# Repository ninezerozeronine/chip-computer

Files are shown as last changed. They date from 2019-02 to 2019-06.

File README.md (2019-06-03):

# 8 bit Computer

   

This is a project to make a basic but fully functional 8 bit computer 
using 7400 series ICs.

The full docs can be found on the Read the Docs: https://eight-bit-computer.readthedocs.io/

# Docs

To build the docs on mac run:

    make clean
    make html

in `docs`.

To build the docs in windows run:

    sphinx-build.exe . _build

in `docs`. This also runs the apidoc command on build with a convenience function in conf.py.

# Tests

To run the tests, run:

    tox -e test

in the root directory.

Run:

    tox -e test -- -m "not slow"

To avoid the slow checks.

To generate a coverage report run:

    tox -e cov

in the root directory.

# Release

    python setup.py sdist bdist_wheel
    python -m twine upload dist/*

# License

The content of this project itself is licensed under the
[Attribution-ShareAlike 4.0 International
license](http://creativecommons.org/licenses/by-sa/4.0/), and any source code used
in conjunction with the project is licensed under the [MIT
license](http://opensource.org/licenses/mit-license.php).

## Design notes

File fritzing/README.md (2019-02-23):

The custom_parts folder contains copies of the bins and parts folders that Fritzing creates in the user home area (C:\Users\<user>\My Documents\Fritzing on Windows).

It's primarily a backup for the custom parts used in the design stage, but feel free to try and modify the files (bins/my_parts.fzb seems to be the one to edit) if you would like to copy them for use in your own project.

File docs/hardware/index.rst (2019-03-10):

Hardware
========

.. toctree::
   :maxdepth: 2
   :caption: Hardware:

   hct_vs_ls
   fanout
   materials_and_tools
   edge_detection
   debouncing
   eeprom_programmer
   safe_clock_enable
   open_collector

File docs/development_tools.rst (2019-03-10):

Development Tools
=================

.. _logisim:

Logisim
-------

.. _fritzing:

Fritzing
--------

.. _falstad:

Falstad Circuit Simulator
-------------------------

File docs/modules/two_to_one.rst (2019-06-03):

.. _two_to_one:

2:1 Selector
============

The 2:1 selector outputs one of two 8 bit inputs. Also known as a multiplexer.

Interface and Operation
-----------------------

This is the interface of a 2:1 selector:

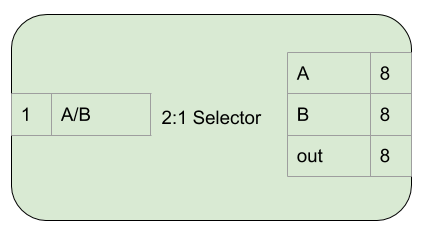
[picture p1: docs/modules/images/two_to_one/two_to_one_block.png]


This is how it operates:

+------+-----------+-----------------------------------------------+
| Name | Bit width | Description                                   |
+======+===========+===============================================+
| A    | 8         | First input                                   |
+------+-----------+-----------------------------------------------+
| B    | 8         | Second input                                  |
+------+-----------+-----------------------------------------------+
| out  | 8         | Output, either A or B.                        |
+------+-----------+-----------------------------------------------+
| A/B  | 1         | When low, A is output, when high, B is output |
+------+-----------+-----------------------------------------------+

Implementation
--------------

- Two 74HCT157s are used to choose between the two inputs.
- LEDs with current limiting resistors are used to display the output.

Due to 2:1 selectors being required in different parts of the computer,
the layout on the breadboard of A, B and out sometimes need to differ.

This is the `A B out` layout:

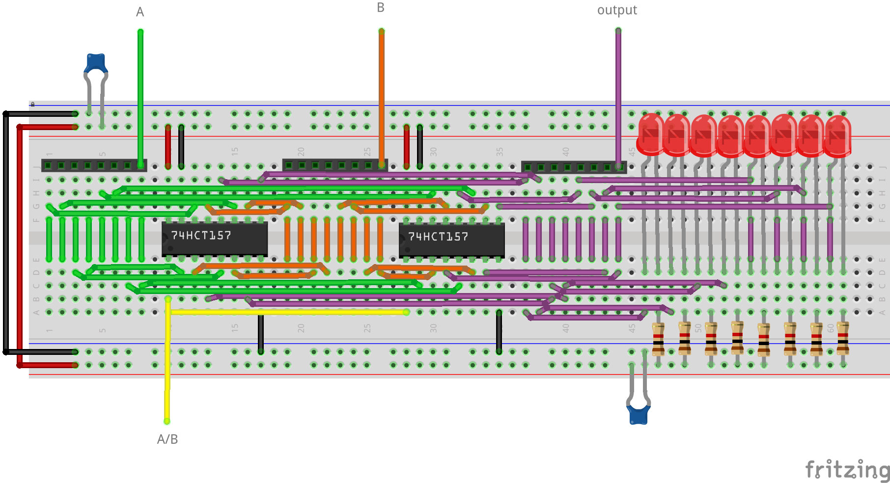
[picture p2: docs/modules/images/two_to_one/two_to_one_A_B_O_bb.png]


This is the `out A B` layout:

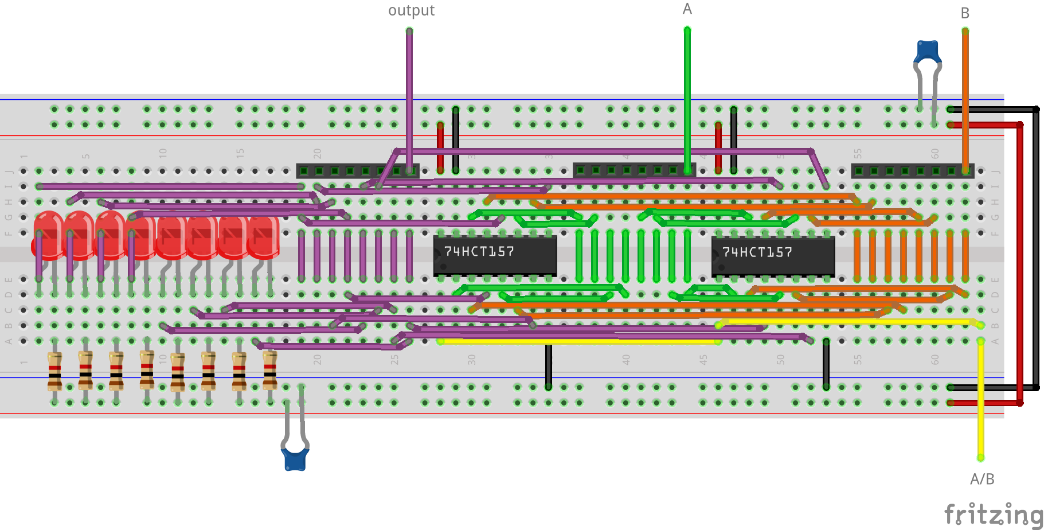
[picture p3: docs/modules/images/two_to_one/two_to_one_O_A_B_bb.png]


Different coloured wires are used in the :ref:`fritzing` images above to help
track the A, B and out bits. When creating the computer only green wire was
available :(.

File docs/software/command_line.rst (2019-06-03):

Command Line Tools
==================

.. _command_line_assemble:

ebc-assemble
------------

.. argparse::
   :ref: eight_bit_computer.cli.get_assemble_parser
   :prog: ebc-assemble

.. _command_line_gen_roms:

ebc-gen-roms
------------

.. argparse::
   :ref: eight_bit_computer.cli.get_gen_roms_parser
   :prog: ebc-gen-roms

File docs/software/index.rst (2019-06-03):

Software
========

.. toctree::
   :maxdepth: 2
   :caption: Key functionality:

   assembler

.. toctree::
   :maxdepth: 2
   :caption: Command line utilities:

   command_line

.. toctree::
   :maxdepth: 3
   :caption: Source Documentation:

   source/eight_bit_computer

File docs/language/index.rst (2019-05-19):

.. _language:

Language
========

The language of the computer is broadly defined with the following terms:

+--------------------------+---------------------------------------------------------------------------------------------------------------------------------------------------------------------------------------------------------------+
| Name                     | Description                                                                                                                                                                                                   |
+==========================+===============================================================================================================================================================================================================+
| Assembly / Assembly code | Collective name for operations in sequence to form a program. The input to the assembler.                                                                                                                     |
+--------------------------+---------------------------------------------------------------------------------------------------------------------------------------------------------------------------------------------------------------+
| Token                    | A set of characters separated from other characters by spaces at the beginning and end. E.g the assembly line ``LOAD [#123] B`` has 3 tokens: ``LOAD`` ``[#123]`` and ``B``.                                  |
+--------------------------+---------------------------------------------------------------------------------------------------------------------------------------------------------------------------------------------------------------+
| Operation                | A specific, simple step that the computer can perform. E.g. add the value in a given register to the accumulator, or copy a value in one register to another.                                                 |
+--------------------------+---------------------------------------------------------------------------------------------------------------------------------------------------------------------------------------------------------------+
| Operation code / Op code | A unique code used to identify an operation, e.g. ``AND``, ``JUMP``, or ``ADD``.                                                                                                                              |
+--------------------------+---------------------------------------------------------------------------------------------------------------------------------------------------------------------------------------------------------------+
| Operation Argument       | A value passed to an operation to specify it's behaviour. E.g. passing ``B`` to the ``ADD`` operation to specify that the value in register B should be added to the accumulator register.                    |
+--------------------------+---------------------------------------------------------------------------------------------------------------------------------------------------------------------------------------------------------------+
| Instruction              | A fully specified operation, e.g. a copy from B to C or setting the A register to a value. Effectively a line of assembly.                                                                                    |
+--------------------------+---------------------------------------------------------------------------------------------------------------------------------------------------------------------------------------------------------------+
| Instruction byte         | A byte that uniquely identifies an instruction.                                                                                                                                                               |
+--------------------------+---------------------------------------------------------------------------------------------------------------------------------------------------------------------------------------------------------------+
| Machine code             | Collective name for the bytes in program memory that form the instructions and constants of a program. The assembler generates machine code.                                                                  |
+--------------------------+---------------------------------------------------------------------------------------------------------------------------------------------------------------------------------------------------------------+
| Machine code byte        | A byte that makes up machine code. Could be an instruction or an constant value.                                                                                                                              |
+--------------------------+---------------------------------------------------------------------------------------------------------------------------------------------------------------------------------------------------------------+
| Microcode                | The pattern of bits that determine the control signals to operate the computer to complete an instruction. The Control Unit contains microcode.                                                               |
+--------------------------+---------------------------------------------------------------------------------------------------------------------------------------------------------------------------------------------------------------+
| Microcode Step           | A single transfer of data via the bus or action of a module occurring on a rising clock edge. The smallest, most specific level of control. An instruction is completed by doing a number of microcode steps. |
+--------------------------+---------------------------------------------------------------------------------------------------------------------------------------------------------------------------------------------------------------+

See the `language table <../_static/language_table.html>`_ (or
:download:`download it <../_static/language_table.csv>`) for a complete listing
of all the machine code and operations with their arguments. The table is
sortable by clicking on the headers (but it's a little slow).

.. toctree::
   :maxdepth: 2
   :caption: Language Elements:

   assembly
   machine_code
   micro_code

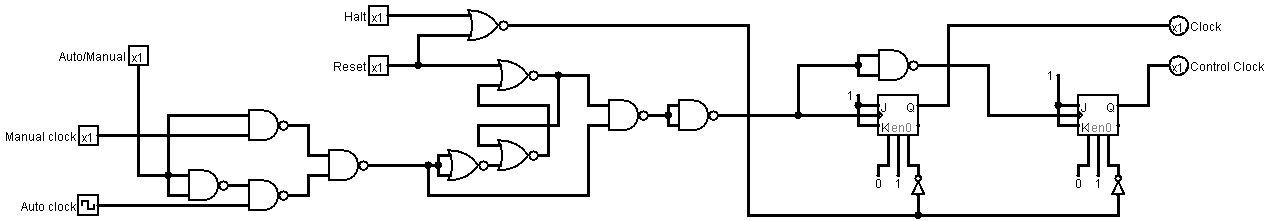
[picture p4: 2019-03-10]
docs/modules/images/clock/clock_schematic_reality.png

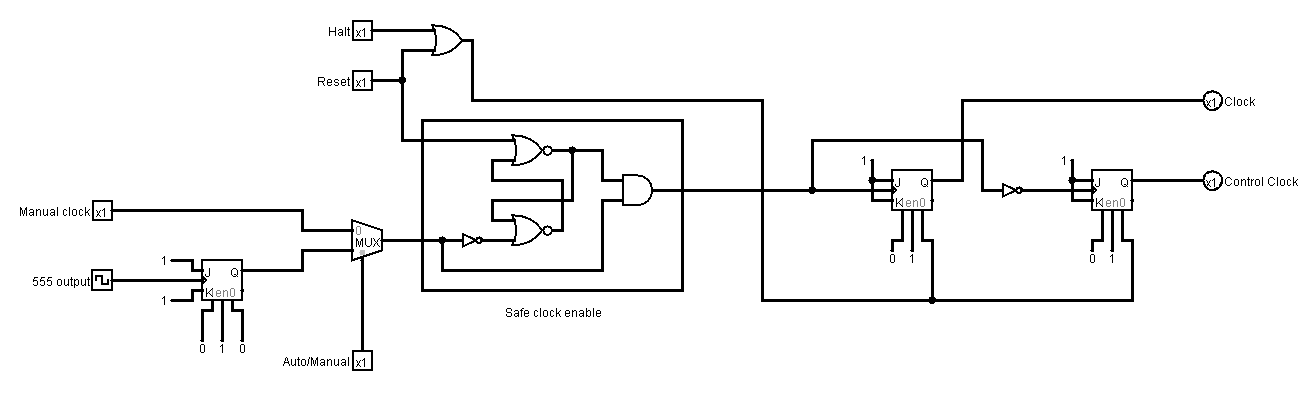
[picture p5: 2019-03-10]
docs/modules/images/clock/clock_schematic_ideal.png

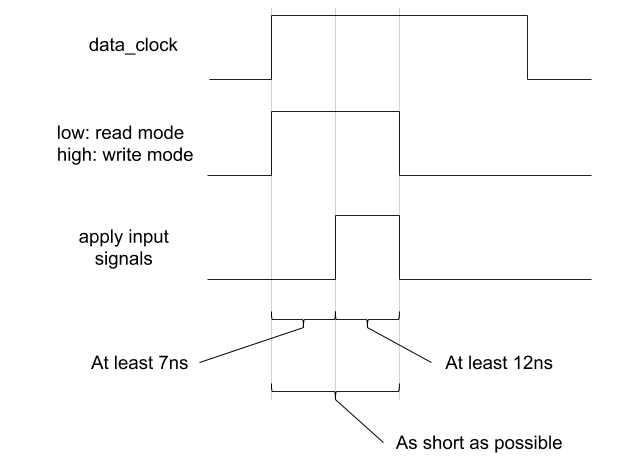
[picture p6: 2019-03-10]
docs/modules/images/ram/ideal_ram_write_control.png

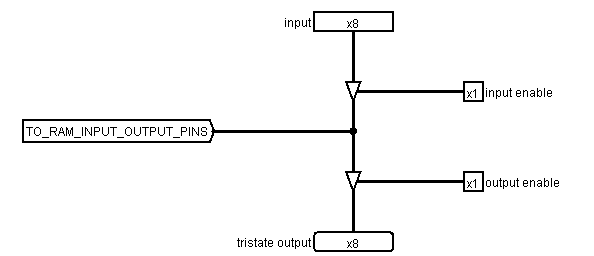
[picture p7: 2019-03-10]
docs/modules/images/ram/input_output_buffers.png

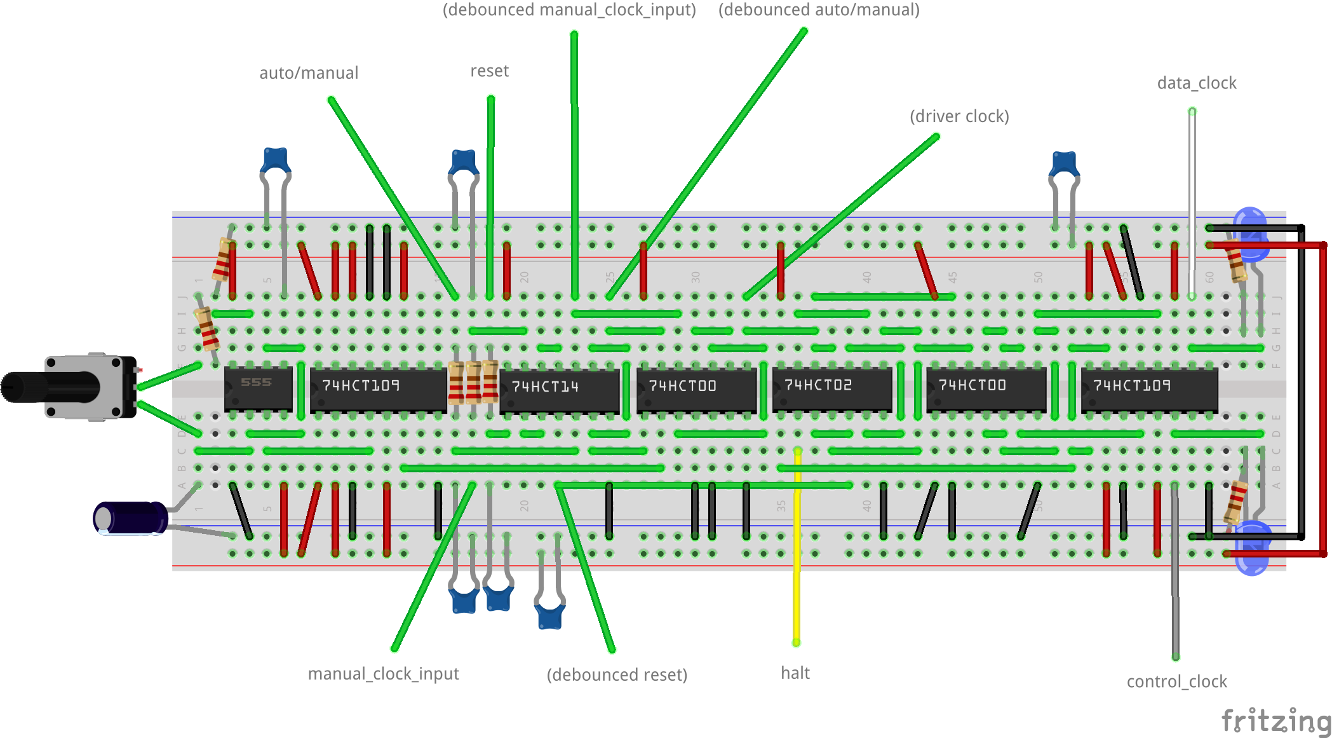
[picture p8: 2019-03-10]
docs/modules/images/clock/clock_bb.png

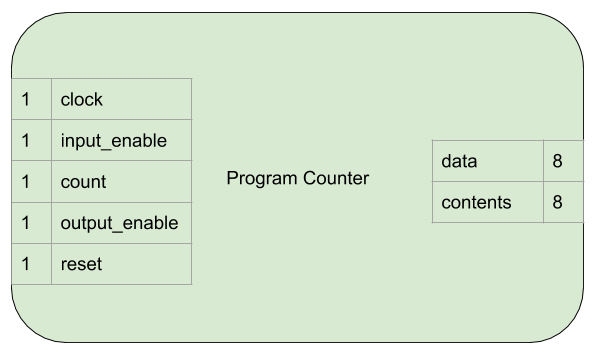
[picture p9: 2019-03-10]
docs/modules/images/program_counter/program_counter_block.png

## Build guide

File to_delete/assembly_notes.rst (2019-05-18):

Some example assembly::

    // This is a comment

        LOAD [#15] ACC
        SET B #0b11010101

    @label1
        COPY ACC A
        COPY A B
        COPY B C
        STORE C [$variable]

    // Another comment
    @label2
        SET SP #255
        JUMP @label1

Handling Constants
-------------------

It's mostly the job of the instruction to identify what it thinks might be a
constant then return this back to the assembler. It can also identify if a
constant (unexpected token) has been given and raise an error.

An instruction will return something like::

    [
        {
            "machine_code": "01101100",
            "constant": "",
        },
        {
            "machine_code": "",
            "constant": "@label",
        },
        {
            "machine_code": "",
            "constant": "#number",
        }
    ]

The constants are then checked by the assembler to see if they conform to
standards and identified. The machine code is then updated to::

    [
        {
            "machine_code": "01101100",
            "constant": "",
        },
        {
            "machine_code": "",
            "constant": "@label",
            "constant_type": "label",
        },
        {
            "machine_code": "",
            "constant": "#number",
            "constant_type": "number",
            "number_value": 123,
        }
    ]

Constants can be @labels, $variables or #numbers

Validating numbers
------------------

#numbers in the assembly are first attempted to be cast to ints. Thay can be
specified in the same way integers are specified in python, e.g.:

- 123
- 0xff
- 0b100101
- 0o77
  
If a number is greater than 255 or less than 128 it's an assembly error.

Assembly errors
---------------

The user needs to know which line of the assembly file an error occurred on.

Should these be execptions?

Assembly steps
--------------

Can raise assembly errors and parsing errors?

Go through every line and extract the following info::

    {
        "line_no": 34,
        "raw_line": "  COPY   ACC   A",
        "cleaned_line": "COPY ACC A",
        "is_label": True
        "label": "@label1",
        "assigned_labels": [],
        
        "variables": [],
        "numbers": [],
        "constants": [],
    }         

Get machine code for the line from the instruction, add it to the dict. Parser
is passed list of constants. Catch Parsing error and re raise as assembly error.

Check numbers are valid - Raise assembly error if there's a bad number

Check for references to labels that haven't been declared. Raise assembly error
if something goes wrong.

Warn about unused labels

Aggregate labels onto real instructions

Warn about multiple labels on single instruction

Exceptions
----------

Could raise exceptions to handle assembly errors?

These get raised by the language parsers:

- InstructionParsingError

  - Constant passed when it wasn't expected
  - Too many arguments passed

These get raised during line processing

- LineProcessingError

  - Invalid label definition
  - Invalid variable definition
  - Invalid label used
  - Invalid variable used
  - 

These get raised during assembly:

- AssemblyError

  - InstructionBytesError
  - UndeclaredLabelError
  - GlobalVariablesError
  - IncorrectNumberError
  - IncorrectLabelNameError
  - IncorrectVariableNameError
  - ParsingError
  - UnmatchedInstructionError

Have a layer of indirection between the assembly and the instructions.
All the instructions need to know is that they've been passed an
immediate value. It's up to the assembler to eventually resolve that immediate
value into:

- An actual number (43)
- A reference to a label (e.g for a jump instruction)

It's the assemblers job to resolve references to @labels (and eventually
$variables). The instructions will need to pass back some kind of placeholder.

Does the assembler just need to say: "You were passed a constant" to the
instruction? And the instruction will pass say: "Here's where to insert that
constant in the machine code"? It needs to be able to pass back some kind of
identifier so that an @label or $variable can later be resolved once it's buried
in the machine code.

What happens if there's some assembly like this::

        %My comment

    @label1
        COPY ACC A
        COPY A B
        COPY B C

    @label2
    @label3
    @label4
        COPY SP C
        COPY A B
        COPY B C

Do @label2, 3 and 4 all mean the COPY SP C line? No, this is invalid. the
assembly will fail

Here's some example data structures::

    assembly_line = {
        "input_line_no": 34,
        "input_line": "  COPY   ACC   A",
        "cleaned_input_line": "COPY ACC A",
        "labels": None,
    }

    machine_code_line {
        "data": "00101010",
    }

    machine_code_line {
        "data": "@label1",
    }

    machine_code_line {
        "data": "11010110",
        "label": "@label2"
    }

I quite like the idea of the machine_code_line structure. If the data is an
@label or $variable then the assembler will know to replace it.

Instructions can keep things simple and return a list of program bytes,
including anything immediate. eg::

    [
        "00101010",
        "IMM",
    ]

Then it's up to the assembler to replace the immediate values with the @label or
$variable in the original assembly line.

As some point the assembler will need to resolve the labels to actual lines in
the machine code.

The assembler needs to be able to cope with:

- LOAD [$variable] A
- LOAD [#123] A
- LOAD [@label] A <- weird, but whatever
- LOAD [ACC] B
- STORE A [$variable]
- STORE A [@label] <- weird, but whatever
- STORE A [#123]
- SET A #123
- JUMP @label
- JUMP B
- JUMP $variable  <- weird, but whatever
- JUMP_IF_FLAG ZERO #123
- JUMP_IF_FLAG ZERO @label
  
Perhaps $variables, @labels and #numbers get converted to IMM by the assembler?
The brackets can just be in the assembly side as a reminder when programming?

Instructions only need to be able to deal with ACC, A, B, C, SP, PC, IMM?

Given ``LOAD [$variable] A`` the assembler should only replace $variable to
arrive at: ``LOAD [IMM] A``.

A user shouldn't be able to write things like:

- ``LOAD [IMM] A``
- ``LOAD [SP+/-] A``
- ``LOAD [SP+/-] IMM``
- ``JUMP SP+/-``
  
The assembler won't end up being able to replace that with a real value later.
It would also trick the instruction matcher as the assembler is meant to pass
IMM to designate an immediate value.

An instruction should be responsible for determining if the line is valid.

Should the assembler inform the instruction if it's being passed a
placeholder/immediate value?

 Could do:

- A list of allowed tokens in assembly files
- A special function that the assembler calls if it's passing through a
  placeholder

We need to be able to point the user back at at line in the assembly file to:

- Warn if a line has multiple labels
- Warn if a label is unused
- Error if you try to jump to an undefined label
  
Does this mean resole @labels while parsing the raw lines?

Constants start with a # but could be int, binary or hex. #i #b #h and it
defaults to int? Use python notation and then ``int(value_string, 0)`` e.g.

- #123
- #0x4f
- #0o77
- #0b1001010

Tests!

- Assembly files with only @labels in
- What happens when you do LOAD [[#123]] A
- Assembly files with only comments
- assembly files with only empty lines
- Passing nothing into a LOAD, e.g LOAD [] A

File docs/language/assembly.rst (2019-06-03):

Assembly
========

Assembly code provides a way to specify instructions for the computer to
perform in a more human readable from than machine code

Assembly operations and arguments to specify their behaviour can be saved in an
assembly file and passed to an assembler to convert them to machine code that
the computer can then execute.

These are the operations and other assembly constructs that can be used to
create a valid assembly file.

Arithmetic Operations
---------------------

ADD
^^^

The ``ADD`` operation adds the value held in the specified module (or a
constant) to the accumulator. The ALU flags generated by this operation are
stored.

The possible usages are:

 - ``ADD A``
 - ``ADD B``
 - ``ADD C``
 - ``ADD CONST``

ADDC
^^^^

SUB
^^^

SUBB
^^^^

LSHIFT
^^^^^^

LSHIFTC
^^^^^^^

INCR
^^^^

DECR
^^^^

Data Operations
---------------

COPY
^^^^

The ``COPY`` operation copies the value from a source module to a destination
module. This overwrites the current value of the destination register. It
requires a single machine code byte in program memory.

It is used by specifying the source module as the first argument and the
destination module as the second.

The possible usages are:

 - ``COPY ACC A``
 - ``COPY ACC B``
 - ``COPY ACC C``
 - ``COPY ACC SP``
 - ``COPY A ACC``
 - ``COPY A B``
 - ``COPY A C``
 - ``COPY A SP``
 - ``COPY B ACC``
 - ``COPY B A``
 - ``COPY B C``
 - ``COPY B SP``
 - ``COPY C ACC``
 - ``COPY C A``
 - ``COPY C B``
 - ``COPY C SP``
 - ``COPY PC ACC``
 - ``COPY PC A``
 - ``COPY PC B``
 - ``COPY PC C``
 - ``COPY PC SP``
 - ``COPY SP ACC``
 - ``COPY SP A``
 - ``COPY SP B``
 - ``COPY SP C``

LOAD
^^^^

The ``LOAD`` operation loads a value from data memory into a module.

It is used by specifying the position in memory as the first argument and the
destination module as the second. The position in memory can be a module or a
constant and is encased in square parentheses.

The possible usages are:

 - ``LOAD [ACC] ACC``
 - ``LOAD [ACC] A``
 - ``LOAD [ACC] B``
 - ``LOAD [ACC] C``
 - ``LOAD [A] ACC``
 - ``LOAD [A] A``
 - ``LOAD [A] B``
 - ``LOAD [A] C``
 - ``LOAD [B] ACC``
 - ``LOAD [B] A``
 - ``LOAD [B] B``
 - ``LOAD [B] C``
 - ``LOAD [C] ACC``
 - ``LOAD [C] A``
 - ``LOAD [C] B``
 - ``LOAD [C] C``
 - ``LOAD [PC] ACC``
 - ``LOAD [PC] A``
 - ``LOAD [PC] B``
 - ``LOAD [PC] C``
 - ``LOAD [SP] ACC``
 - ``LOAD [SP] A``
 - ``LOAD [SP] B``
 - ``LOAD [SP] C``
 - ``LOAD [CONST] ACC``
 - ``LOAD [CONST] A``
 - ``LOAD [CONST] B``
 - ``LOAD [CONST] C``

STORE
^^^^^

PROGLOAD
^^^^^^^^

PROGSTORE
^^^^^^^^^

PUSH
^^^^

POP
^^^

SET
^^^

The ``SET`` operation will set a module in the computer to a given
constant value.

It is used by specifying a module as the first argument, then the value to set
it to as a constant.

It requires two machine code bytes in program memory. Consider the
:ref:`setzero` operation if the constant is zero.

The possible usages are:

 - ``SET ACC CONST``
 - ``SET A CONST``
 - ``SET B CONST``
 - ``SET C CONST``
 - ``SET SP CONST``

.. _setzero:

SETZERO
^^^^^^^

Program Control Operations
--------------------------

NOOP
^^^^

JUMP
^^^^

The ``JUMP`` operation will set the program counter to a value.

The possible usages are:

 - ``JUMP ACC``
 - ``JUMP A``
 - ``JUMP B``
 - ``JUMP C``
 - ``JUMP SP``
 - ``JUMP CONST``
 - ``JUMP [ACC]``
 - ``JUMP [A]``
 - ``JUMP [B]``
 - ``JUMP [C]``
 - ``JUMP [SP]``
 - ``JUMP [PC]``
 - ``JUMP [CONST]``

JUMP_IF_LT_ACC
^^^^^^^^^^^^^^

JUMP_IF_LTE_ACC
^^^^^^^^^^^^^^^

JUMP_IF_EQ_ACC
^^^^^^^^^^^^^^

JUMP_IF_GTEQ_ACC
^^^^^^^^^^^^^^^^

JUMP_IF_GT_ACC
^^^^^^^^^^^^^^

JUMP_IF_EQ_ZERO
^^^^^^^^^^^^^^^

JUMP_IF_POSITIVE_FLAG
^^^^^^^^^^^^^^^^^^^^^

JUMP_IF_NEGATIVE_FLAG
^^^^^^^^^^^^^^^^^^^^^

JUMP_IF_OVERFLOW_FLAG
^^^^^^^^^^^^^^^^^^^^^

The ``JUMP_IF_OVERFLOW_FLAG`` operation will set the program counter to the
value of a given constant if the overflow flag is high.

The possible usages are:

 - ``JUMP_IF_OVERFLOW_FLAG CONST``

JUMP_IF_NOT_OVERFLOW_FLAG
^^^^^^^^^^^^^^^^^^^^^^^^^

JUMP_IF_UNDERFLOW_FLAG
^^^^^^^^^^^^^^^^^^^^^^

JUMP_IF_NOT_UNDERFLOW_FLAG
^^^^^^^^^^^^^^^^^^^^^^^^^^

JUMP_IF_ZERO_FLAG
^^^^^^^^^^^^^^^^^

JUMP_IF_NOT_ZERO_FLAG
^^^^^^^^^^^^^^^^^^^^^

CALL
^^^^

RETURN
^^^^^^

HALT
^^^^

Logical Operations
------------------

NOT
^^^

AND
^^^

NAND
^^^^

OR
^^

NOR
^^^

XOR
^^^

NXOR
^^^^

Constants
---------

Constants are values that the assembler will convert to machine code bytes for
operations that require data in the machine code. For example, a jump to an
explicit index in program memory, or setting a register to an explicit value.

Labels
^^^^^^

A label binds to the line of assembly that follows it. Once assembly is complete
the label's value is the index in program memory of the instruction byte that
followed the label definition. E.g. If an assembly file looked like this:

.. code-block:: text

        LOAD [#123] A
        ADD A

    @label
        SET B #42

The value of ``@label`` would be 3. The instruction byte corresponding to ``SET
B #42`` is at program memory index 3. ``LOAD [#123] A`` takes 2 bytes, ``ADD A``
one, and ``SET B #42`` is the byte after that.

Labels are typically used by jump operations.

A label is a token that starts with the ``@`` character followed by any letter or
an underscore, then any alphanumeric or an underscore. E.g.:

 - ``@label``
 - ``@label_1``
 - ``@_other_label``
   
Labels must be unique.

A label is defined by putting it on a line by itself.

Variables
^^^^^^^^^

Variables are named aliases for indexes into data memory. They can be
predeclared by putting them by themselves on a line or declared as they are
used by using them as an argument.

The index for a given variable is determined by the assembler. As it parses
assembly lines from the start of the file to the end, addresses are assigned to
variables as they are encountered in the file. E.g. for the following assembly:

.. code-block:: text

        $variable1
        COPY A ACC
        LOAD [$variable2] A

variable1 is predeclared, variable2 is declared as it's used. Once assembled,
variable1 is an alias for 0, variable2 is an alias for 2.

A variable is a token that starts with the ``$`` character followed by any letter or
an underscore, then any alphanumeric or an underscore. E.g.:

 - ``$variable``
 - ``$variable1``
 - ``$_other_variable``

Numbers
^^^^^^^

Numbers are integer values. In most cases they within the range -127 to 255
(inclusive). This range comes from the minimum and maximum values that 8 bits,
or 8 bits with 2's compliment encoding can hold.

A number is a token that starts with the ``#`` character and is followed by any
valid Python integer definition. E.g. 

 - ``#123`` (decimal)
 - ``#-5`` (decimal)
 - ``#0b00010010`` (binary)
 - ``#-0b0101`` (binary)
 - ``#0xA2`` (hex)
 - ``#0o107`` (octal)

Comments
--------

Comments are parts of the assembly file ignored by the assembler.

A comment is anything after and including ``//`` on a line until the end of the
line.

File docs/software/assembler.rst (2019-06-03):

.. _sw_assembler:

Assembler
=========

The :mod:`~eight_bit_computer.assembler` module is responsible for taking lines
of assembly code and processing it to generate equivalent machine code.

It is passed a list of strings which are the lines of the assembly file. Each
line is then processed and the information about the line stored in :func:`a
dictionary<.get_assembly_line_template>`.

During processing each line is checked to see if it's a constant definition, if
not, it's treated as an assembly line and
:func:`parsed into machine code bytes<.machine_code_bytes_from_line>`.

The line is passed to :func:`each operation<.get_all_operations>` to attempt to
generate the machine code bytes. The operations can expect certain tokens on the
line to be constants and are identified as such and returned to the assembler.
The constants are then :func:`validated and identified
<.validate_and_identify_constants>` and the machine code bytes added to the
dictionary of information about the line of assembly.

With all the lines processed, machine code bytes generated and constants
identified, the assembler :func:`checks for overall validity and structure
<.check_structure_validity>` The assembler then performs global operations that
need to take the entire assembly code into account:

- :func:`Assigning indexes to the machine code bytes<.assign_machine_code_byte_indexes>`
- :func:`Assigning labels to machine code bytes<.assign_labels>`
- :func:`Resolving labels to indexes in program memory<.resolve_labels>`
- :func:`Resolving number constants to bytes<.resolve_numbers>`
- :func:`Resolving variable constants to indexes in data memory<.resolve_variables>`
  
With these checks, assignments and resolutions complete, the final assembly
line dictionaries are returned.

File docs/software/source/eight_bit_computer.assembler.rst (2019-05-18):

eight\_bit\_computer.assembler module
=====================================

.. automodule:: eight_bit_computer.assembler
    :members:
    :undoc-members:
    :show-inheritance:

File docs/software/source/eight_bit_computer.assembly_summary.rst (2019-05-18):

eight\_bit\_computer.assembly\_summary module
=============================================

.. automodule:: eight_bit_computer.assembly_summary
    :members:
    :undoc-members:
    :show-inheritance:

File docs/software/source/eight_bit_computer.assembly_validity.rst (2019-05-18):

eight\_bit\_computer.assembly\_validity module
==============================================

.. automodule:: eight_bit_computer.assembly_validity
    :members:
    :undoc-members:
    :show-inheritance:

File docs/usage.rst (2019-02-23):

Usage
=====

Setup
-----

Inputting Programs
------------------

Running and Resetting
---------------------

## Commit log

2018-02-07 Initial commit of Python rom code, circuit scehematic and game description
2018-02-10 Add rom decoding with debug prints
2018-02-10 Add rom printer
2018-02-11 Minor name changes to signals. Lots of work on schematic
2018-02-11 Add tunnels to schematic for monitoring
2018-02-12 Fix bugs in add instructions. Add output to schematic. First working version.
2018-02-12 Add all opcodes to fetch. Small tweaks to circuit
2018-03-02 Add led outputs, make local and release buils scripts
2018-04-08 Start machine code and assembly pages in docs
2019-01-07 Add Fritzing files
    [RAM.fzz, alu.fzz, control_unit.fzz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]
2019-02-07 Add latest copies of fritzing files
    [RAM.fzz, alu.fzz, alu2.fzz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]
2019-02-17 Add assembler and disassembler stubs
2019-02-19 Start making labels in logisim. Switch order of SP and PC
2019-03-03 Add latest Fritzing files
    [RAM.fzz, alu.fzz, alu2.fzz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]
2019-03-10 Added latest frizing design and custom part files. Cleaned up old breadboard images.
    [control_unit.fzz, ram.fzz, register_input_only_right.fzz]
2019-03-12 Make assembly notes
2019-03-13 More thoughts on assembler
2019-03-17 Add bit of example code for assembly
2019-03-17 Flesh out assembler python example
2019-03-18 More planning/notes for assembler. Slow progress
2019-03-19 Skeleton of assembler modtly complete, start docstrings. Add exceptions.
2019-03-20 assembler docstrings mostly finished. Starting to code assembler.
2019-03-20 Restruture tests. Add one assembler test.
2019-03-21 Moved to modification in place methodology. Assembler now in it's own module. Update test structure to reflect assembler
2019-03-25 Mostly finish assembler
2019-03-25 More assembler tests. Refactor operations into operations module.
2019-03-28 Start converting tests to pytest. Continue writing tests for assembler
2019-03-30 Finish up most assembly tests. Convert some old tests to pytest
2019-03-31 Convert a couple more old assembler tests
2019-04-20 Start work on generic assembly line parser
2019-04-24 Bit more work on generic parser tests. Start writing assembly extractor. Deliberately break assembler as a new function needs to be written.
2019-04-26 Finish assembly summary generation.
2019-04-27 Converted assembly lines and processed assembly lines to fixtures.
2019-04-28 Re-ordered and added decimal print to machine code byte byte val prints in summary
2019-05-01 Continue adding assembly validation. Start planning template rename.
2019-05-09 Small tweaks to get assembler working. Some docstring func ref cleanup
2019-05-10 Fix a couple of docstring bugs. Start experimenting with sortable table in docs.
2019-05-11 Update html table for macine code
    [machine-code.csv]
2019-05-12 Start work on Assembly/language documentation
    [machine-code.csv]
2019-05-16 Small tweak to language defs. Start documenting microcode.
    [machine-code.csv]
2019-05-17 Finish microcode docs. Start Assembler docs
2019-05-18 Update clock module images. Finish assembler definition. Finish off some docstrings
2019-05-18 Update referenced to functions in docstrings to easy tilde-dot method. Tiny addition to assembler description.
2019-05-19 Fix langauge table link bug. Rebuild docs. Copy docs for release.
    [language_table.csv]
2019-05-19 Actually updating docs...
    [language_table.csv, machine-code.csv]
2019-05-19 Moved sphinx_docs to docs. Update .gitignore
    [language_table.csv]
2019-05-21 Update control steps for loading and jumping to constants in memory. Add a couple of rom tests. Update readme.
2019-05-26 Finish assemble cli. Add some error checking to assemble main script.
2019-05-27 Document ADD. Make basic ALU ops support consts. Update language table to include consts on jump instructions.
    [language_table.csv]
2019-06-03 Add docs for new assembly operations. Make logisim model represent final computer.
2019-06-03 Update language table to have decimal numbers zero padded
    [language_table.csv]
